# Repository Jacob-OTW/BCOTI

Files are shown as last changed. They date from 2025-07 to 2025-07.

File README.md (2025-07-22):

# BCOTI (Budget-Clip-On-Thermal-Imager)
This project is about building a Clip-On-Thermal-Imager (COTI) for Analog night vision goggles, similar to the Jerry-C, PAS29A/B, etc. yourself.

The current version uses a 256x192@12um sensor with a 9.1mm lens. This combined with the LZE039 and 25mm DCX lens, gives you a 1x 17°x13° thermal overlay in your NVGs. At the moment the image is cropped to a 13°x13° Rectangle.

Cropping it to a 13° circle is also an option by modifying the shape of the `Display_Spacer.step` model.

The unit is powered by a standard USB-C power source delivering 5v.

# User Manual

## Setting image settings

The BCOTI uses the Wi-Fi interface of the esp32 board to act as a web server to host a basic WebUI. To start the unit with Wi-Fi enabled, 

1. hold down the push-button and then supply the unit with power, so either plug in your cable (given the poti is already enabled) or enable the poti, keep the button held down for a short moment, then let go.

2. Open your phones Wi-Fi settings and connect to "BCOTI", the password is "wifipass1234"

3. Inside a web browser, open "192.168.4.1".

4. At the top you select the active preset, so the one being both used by the unit in real time, and the one you make changes to.

5. You can either enable or disable a preset, this determines if the preset will be used, or skipped when using the push button on the unit.

6. Once you made all your changes, reboot the unit to run it on the normal mode. Then use the push button to cycle through your active presets.

### Recommended Settings
- Burn protection. This will automatically close the shutter of the thermal camera if you look at something very hot, like a fire, or the sun. Note that when the unit is not powered, the shutter is in the open position, so it's highly recommended you cover the lens when the unit is not in use. Very hot object can burn the actual sensor.
- Auto Shutter. This will do Non-Uni

# Bill-of-materials
Expect to pay about 400€ (EU) or about 500usd (US) for parts when buying in small quantities

| Part | Cost | Link | Comment |
|---|---|---|---|
| Mini2 | 189€ | [AliExpress (256 9.1mm option)](https://www.aliexpress.us/item/1005007938410808.html) | Only the 256 w/ 9.1mm version will work, others won't be 1x with current setup. [Hdaniee Store page incase the link doesn't work](https://www.aliexpress.com/store/1104212749?spm=a2g0o.detail.0.0.5c38Uf2FUf2Fd3), CV256 9.1mm. [For Some it might also be much cheaper to buy on Alibaba](https://www.alibaba.com/product-detail/HDANIEE-Series-Thermal-Imaging-Camera-Module_1601290252342.html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) |
| LZE039 OLED | 98€ | [AliExpress (AV 3color option)](https://www.aliexpress.us/item/1005008087046449.html) | Bare screen + AV driver. |
| Esp32c3 Super Mini | 2.6€ | [AliExpress](https://www.aliexpress.us/item/1005007663345442.html) | They can break during assembly, I'd recommend a 5pc for safety. |
| USB-C Connector Breakout (1x+) | 2.25€  | [AliExpress 2pc ("TYPE-C male 4P" option)](https://www.aliexpress.us/item/1005005870466748.html) | At least 1x for device internal, but can also be used to created really low profile cable for helmet setup. |
| USB-C Port | 1.49€  | [AliExpress ("4P Black" option)](https://www.aliexpress.us/item/1005005768848819.html) | |
| Toggle Switch | 1.19€  | [AliExpress ("3P 11.7ON-OFF-ON R" option)](https://www.aliexpress.us/item/1005008165436395.html) | |
| Poti w/ ON-OFF-switch | 2.59€  | [AliExpress 5pc ("20K Ohm" option)](https://aliexpress.us/item/1005003523748492.html) | Can also be higher resistance value, for voltage divider, without current draw like here, it doesn't really matter |
| M2x4 Screws (11x) | 1.35€  | [AliExpress 50pc (M2 x 50pc, 4mm length option)](https://www.aliexpress.us/item/1005008314123679.html) | I didn't use these exact ones, but should work, otherwise I adjust the hole size for the screw heads |
| M2x3 Heat Inserts (11x) | 9.99€  | [CNCKitchen 100pc](https://cnckitchen.store/products/heat-set-insert-m2-x-3-100-pieces) | Could also get cheaper ones in similar size, but I like these because they give good info about the required hole sizes. Should you get one with a smaller OD, the FreeCad file has a parameter for that. |
| 5mmD 25mmF DCX lens | 41.61$ | [Edmund Optics](https://www.edmundoptics.com/p/5mm-dia-x-25mm-fl-uncoated-double-convex-lens/18171/) | Price is really bad, but haven't found alternative yet. |
| 5x5x5mm right-angle-prism | 1.99€  | [AliExpress](https://www.aliexpress.com/item/1005008430325318.html) | This replaces the surface mirror used in previous versions, look into the change history for more info. [If the link doesn't work, try this one](https://www.aliexpress.com/item/4001089104491.html) |
| 3mm Elastic band (1m) | 1,99€  | [AliExpress ("3mm 10meters" option)](https://www.aliexpress.us/item/1005008987955538.html) | should be between 2mm and 3mm thickness, you won't actually need a meter, but cutting them to the right sizes sometimes takes a few tries. |
| 26AWG Silicone wire | 10.29€ | [AliExpress ("26 AWG 60m" option)](https://www.aliexpress.us/item/1005005450546335.html) | Any 26AWG (or close to) silicone wire will work, would recommend least 3 unique colors though. |
| O-Ring OD32 CS3.1 | 2.49€  | [AliExpress 50pc ("OD32mm CS3.1mm" option)](https://www.aliexpress.us/item/1005008292700053.html) | Kinda optional, it by itself won't water proof the housing, as there are other way water can still get in besides the edge of the camera-cage, but it's a start. |
| 7mm Momentary Button | 2.99€  | [AliExpress 5pc ("PBS-110 NO Black") option](https://www.aliexpress.us/item/1005008777027854.html) | |
| 1.25mm 5pin jst cable | 2.69€  | [AliExpress ("5set 5pin" option)](https://www.aliexpress.us/item/1005008669994352.html) | |
| Heat shrink tubes | 1.69€  | [AliExpress](https://www.aliexpress.us/item/1005008858472748.html) | |

# Build-Guide

## 3d printed parts

Using a dark material which absorbs light instead of reflecting it is highly recommend.

1. Print the `Body_Shell.step`, `PVS14_Lens_Clip.step`, and `Camera_Cage_x_x_deg.step` with a basic 0.12mm layer height profile.
Change the following
    1. Wall-loops to 3x or 4x. 
    2. Infill to about 22% to 35%
    3. Support to tree

    <br>
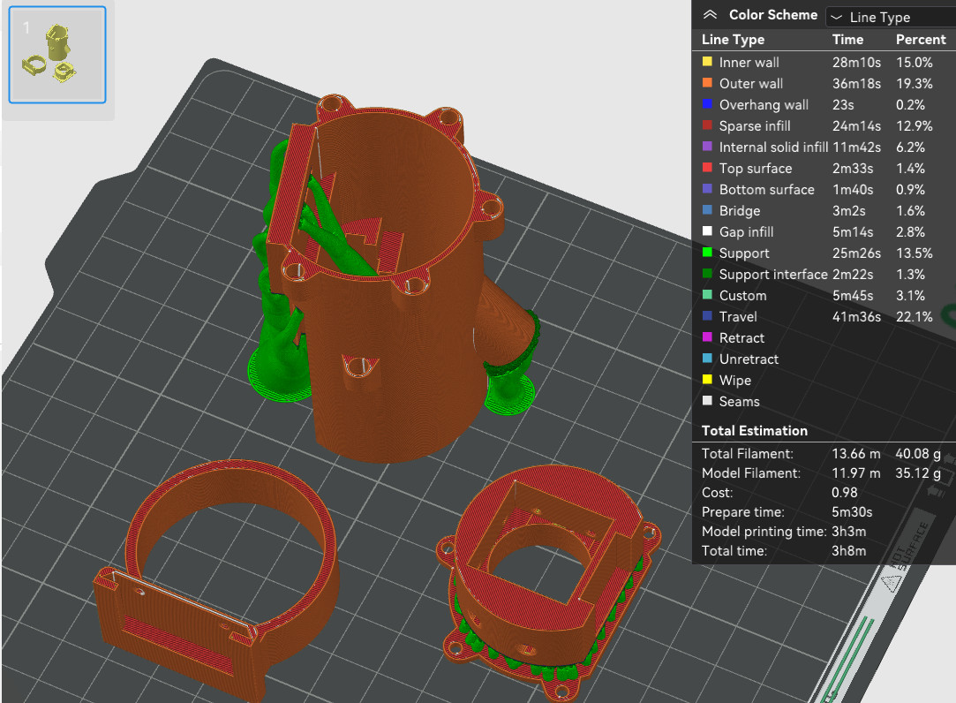
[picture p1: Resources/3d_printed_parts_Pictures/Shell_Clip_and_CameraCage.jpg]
Shell_clip_and_cage_3d_printing
    
    <br>
    I'd recommend adding extra support to the push-button mount hole on the housing shell
    <br>
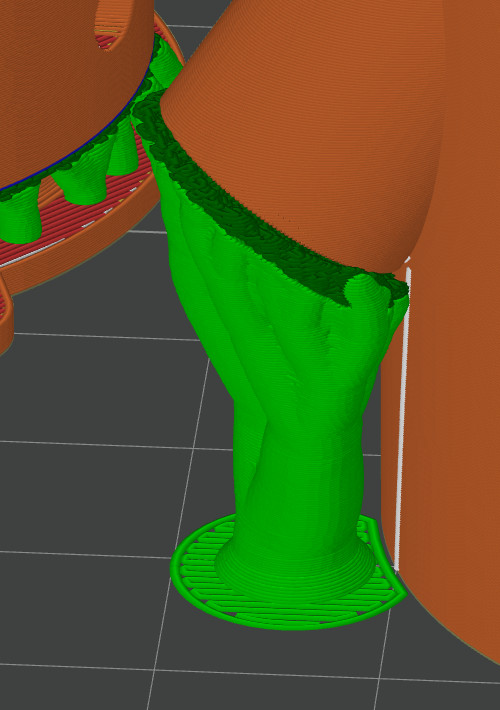
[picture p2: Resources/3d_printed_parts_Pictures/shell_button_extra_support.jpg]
Extra_support
    

2. Print the periscope like shown in the picture. <=0.12mm layer height, and I'd recommend "Snug" supports.
<br>
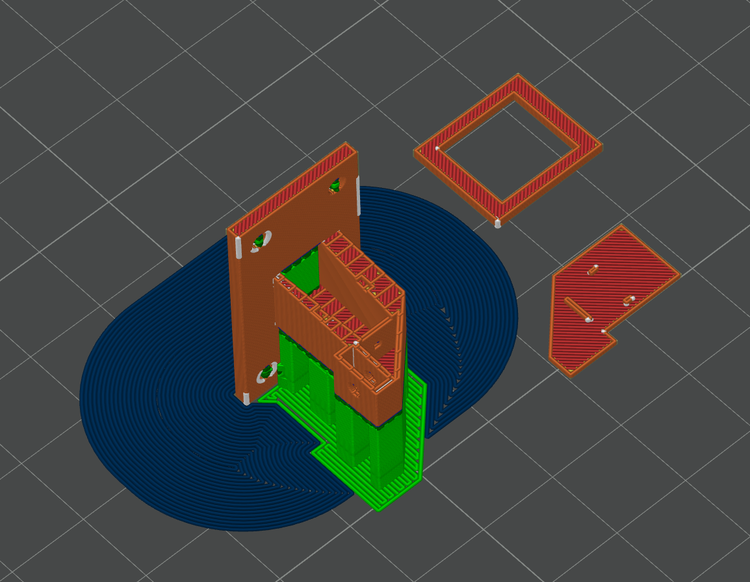
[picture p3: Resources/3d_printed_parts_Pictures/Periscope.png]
Periscope print oriantation

<br>
After the print, press fit the prism and DCX lens into the periscope. After checking functionally, you can glue on the side cover

3. (Optional, but recommended) print the `Bikini_Cover_TPU.step` out of a fairly soft TPU. I printed mine out of 95A Overture TPU

## Electronics

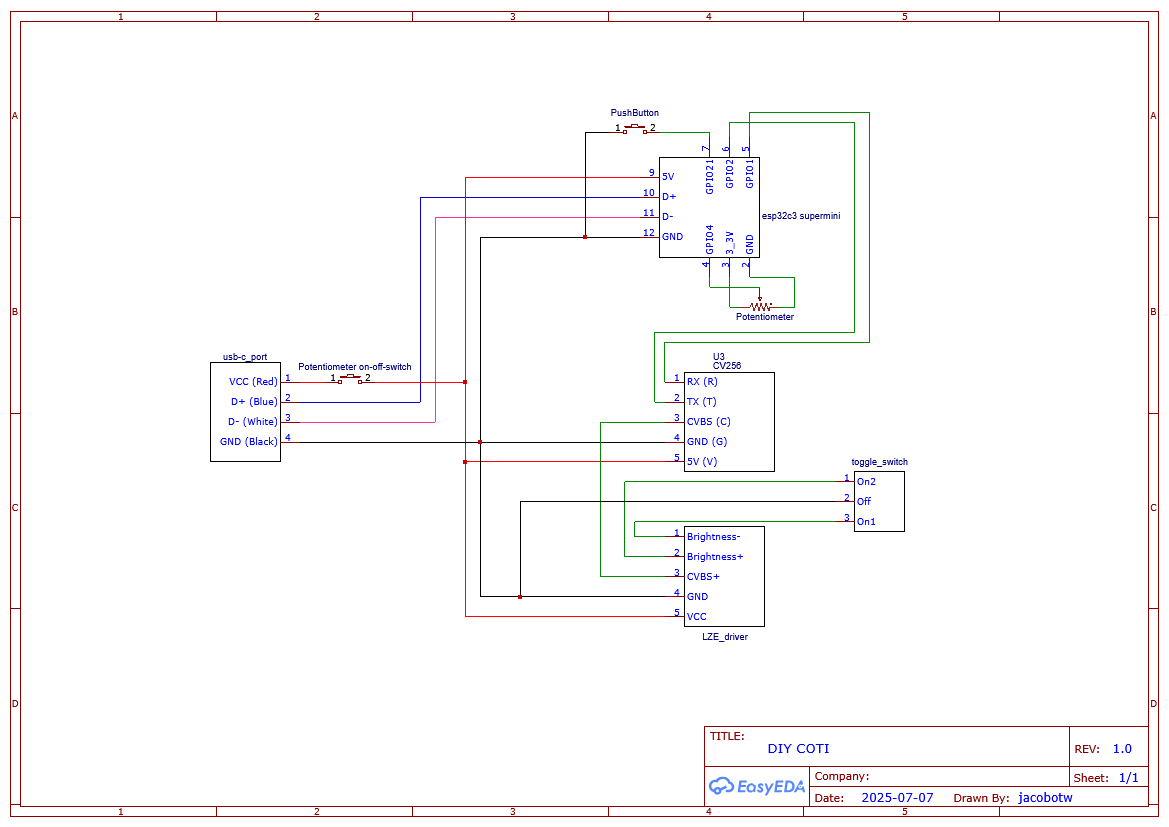
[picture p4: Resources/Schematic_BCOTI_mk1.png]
wiring_diagram


### Step-by-step

Using Heat shrink for all connections where possible is recommended.

1. Cut the cables of the USB-C port to a length of around 80mm.
2. Cut a 1x 80mm piece of (Red) wire. And 3x 30mm pieces of (Red) Wire. These will be your 5V-net. Strip a portion of the installation on one side so that you can twist together the 3x short pieces, then cover in solder.
3. Cut 5x 30mm pieces of black wire. These will be your ground-net. Strip one side and combine the 5pieces, same as you did for the 5v-net.
4. Solder the 80mm piece of (Red) wire, to the potentiometer's on-off-switch.
<br>
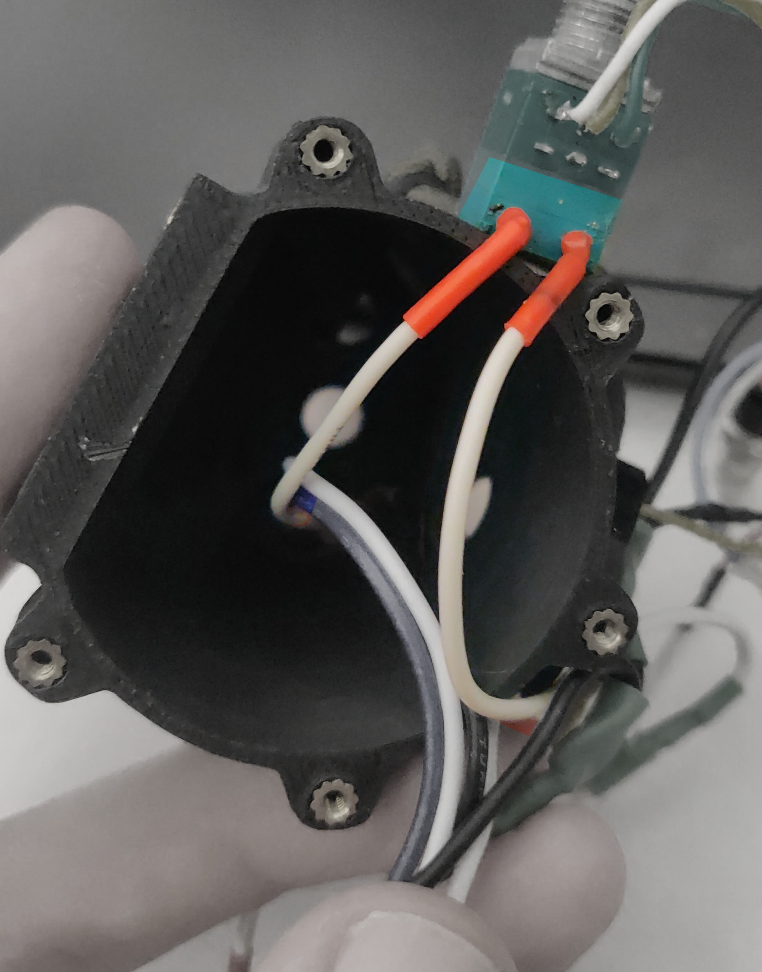
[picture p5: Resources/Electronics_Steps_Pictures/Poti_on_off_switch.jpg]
Poti_On_Off_Switch

(picture shows USB-C Port wire already connector, this is done during assembly)

5. Solder the bundle of 3 (Red) wires to the 80mm piece from the previous step.
<br>
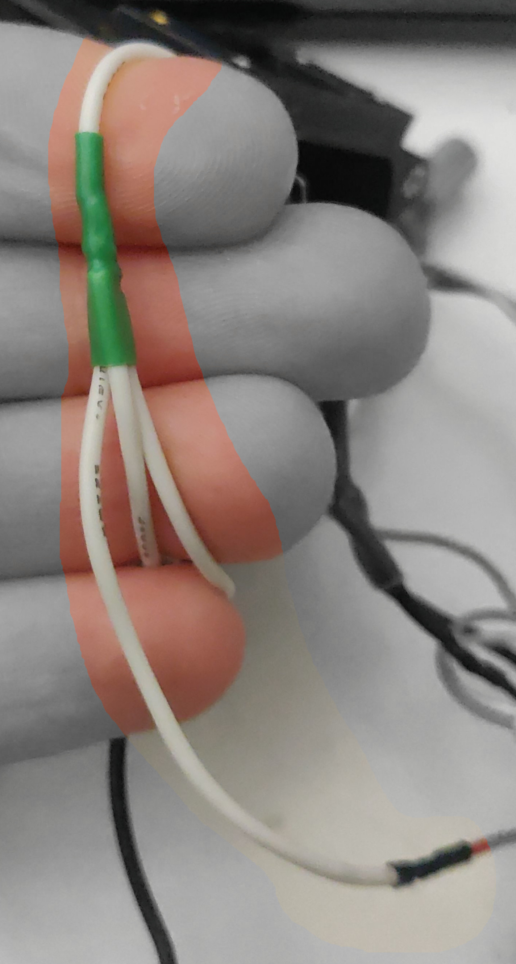
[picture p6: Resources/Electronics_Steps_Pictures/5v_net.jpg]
5v_net


6. Attach the 5v wires, as well as ground to the USB-C breakout board, the display driver connector, and the camera connector, as shown in the diagram.

7. Connect ground wires to the push-button, and on-off-on toggle switch.

8. Cut a 50mm piece of wire, solder one end to the push button, and the other to under side, facing inwards to the esp32c3's GPIO21 pin.
<br>
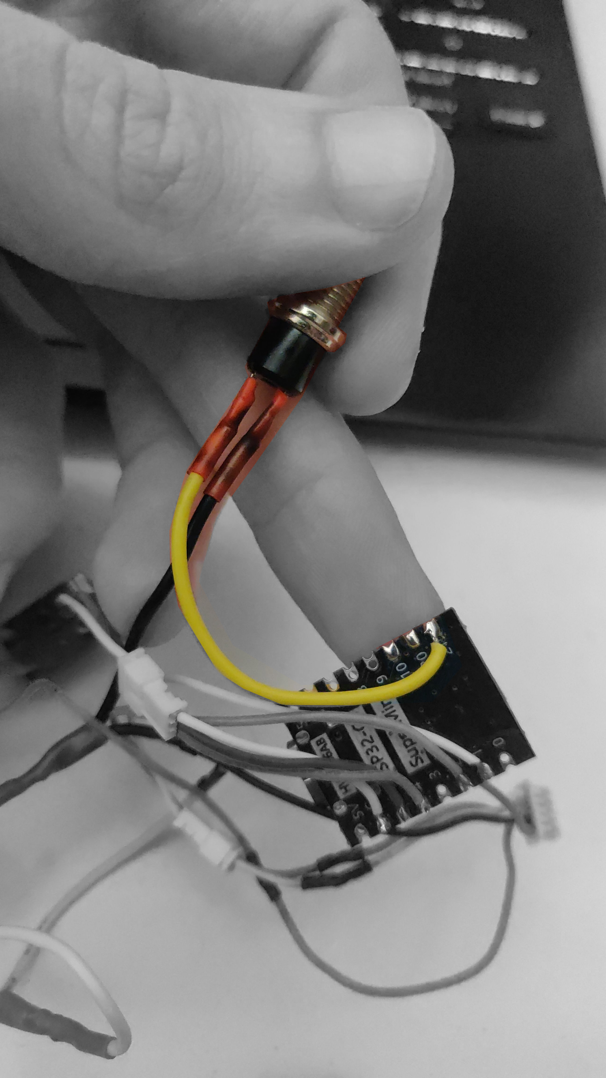
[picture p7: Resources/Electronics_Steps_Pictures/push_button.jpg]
Push_button

9. Cut the `brightness+` and `brightness-` cables of the display driver to a length of about 70mm, then attach them to the `on`-terminals of the toggle-switch.
<br>
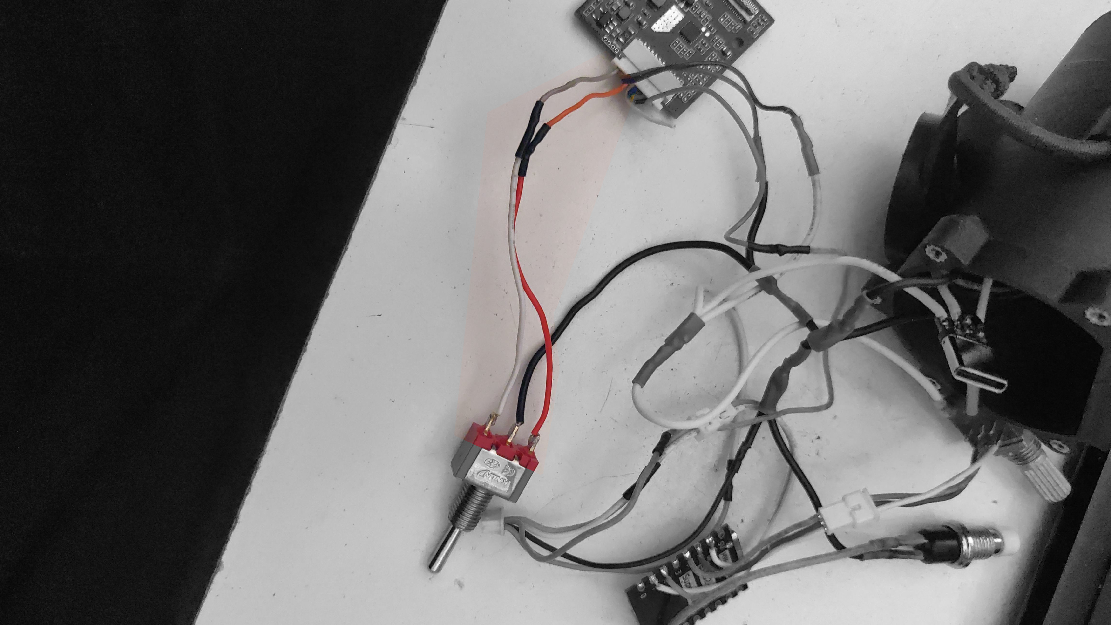
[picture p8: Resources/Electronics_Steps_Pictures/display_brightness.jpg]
Brightness_switch

10. Connect the white wire of the usb-c port to the D- Pad of the USB-C breakout board, and the blue wire to D+.
<br>
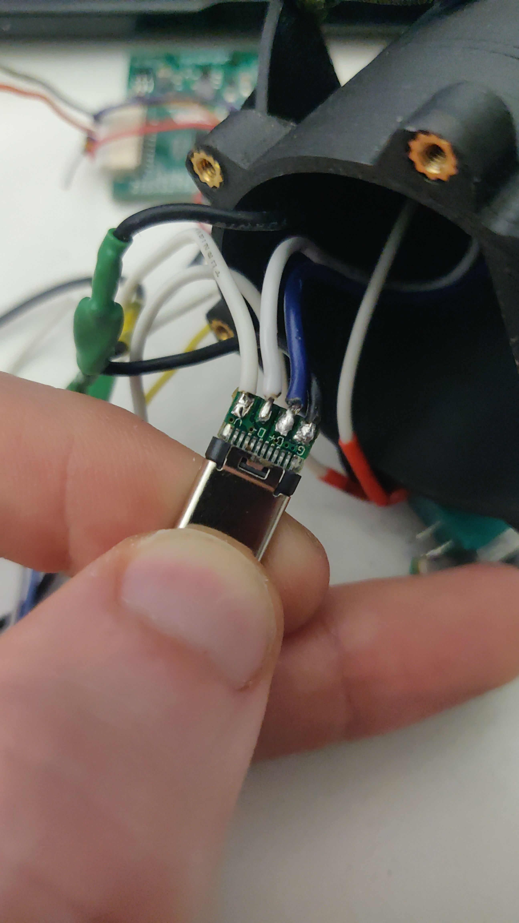
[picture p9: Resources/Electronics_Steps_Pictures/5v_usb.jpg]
USB_C_Port_to_connector

11. Connect the RX wire of the camera to GPIO1, and the TX wire to GPIO2 of the esp32c3 board. The cables should be attached on the underside facing inwards.
<br>
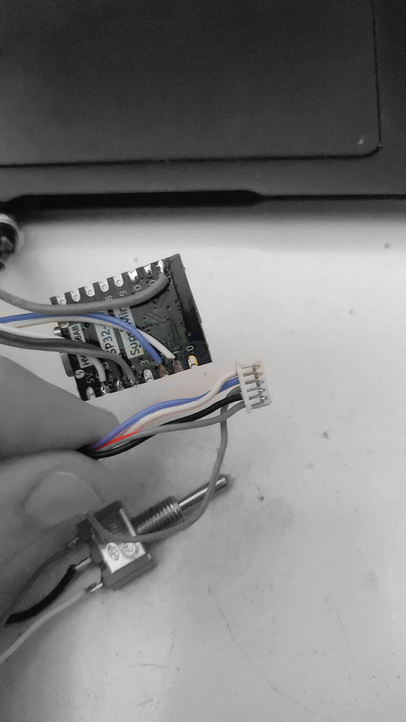
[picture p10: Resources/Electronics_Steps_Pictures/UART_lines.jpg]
UART_lines

12. Using 3x 50mm pieces of wire, connect the potentiometer to the esp32 board like shown in the schematic. Ground should be on the left, sense-wire (GPIO4) in the centre, and 3.3v on the right, that way the power goes from 0v to 3.3v when it's turned up, instead of being reversed.
<br>
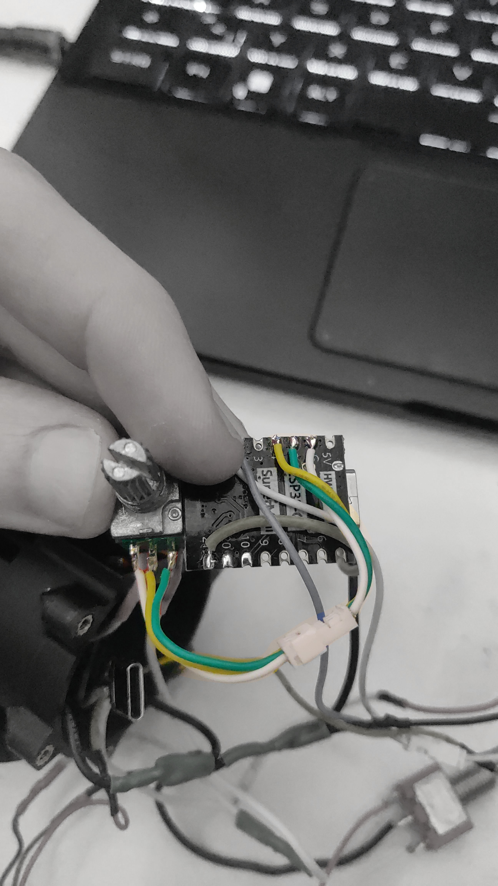
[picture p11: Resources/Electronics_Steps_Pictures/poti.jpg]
Poti_Voltage_Dividier

13. Connect the Video-out of the camera to the `CVBS+` cable of the display driver. Total wire length is recommended at 130mm. 

## Assembly

1. Insert the USB-C Port into the housing.

2. Solder the 5v wire of the Port to the on-off-switch of the potentiometer

3. Insert the potentiometer into the shell (from the inside) with the pins pointing down, and fix in place the with the Nut and washer.
<br>
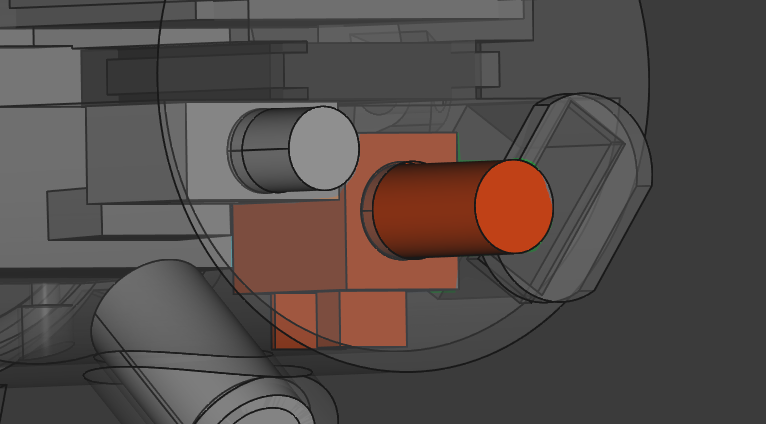
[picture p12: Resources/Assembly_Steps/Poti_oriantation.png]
potentiometer oriantation


4. Insert the Brightness Toggle switch (horizontal orientation), and fix in place with washer and nut.
<br>
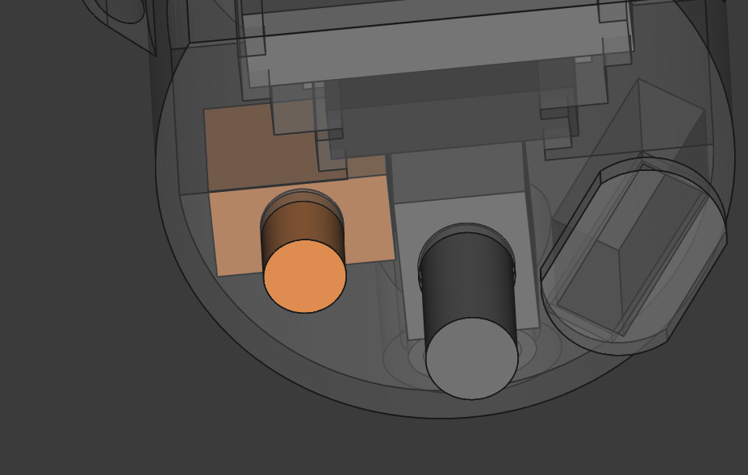
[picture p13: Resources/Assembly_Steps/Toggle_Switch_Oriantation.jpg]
toggle switch oriantation


5. With the USB-Port facing down, and the usb-c breakout connector inserted, insert the esp32 board into the centre slot of the shell
<br>
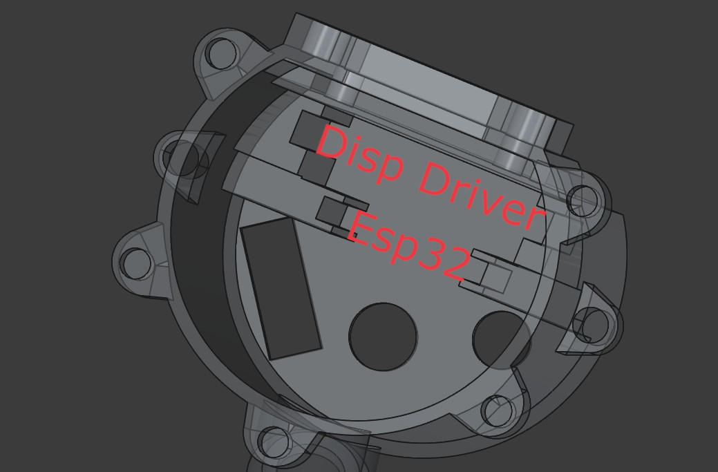
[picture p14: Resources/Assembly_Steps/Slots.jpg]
Shell Slots


6. Disconnect the display from the driver, and insert the FPC through the hole of the slot for the display.

7. Connect the display to the driver again, then insert the driver (with the wires pointing into the shell) into the slot.

8. Insert the push-button into the slot on the bottom of the shell, and fix it in place with the nut and washer.

9. Wrap the O-Ring around the CameraCage, and insert the camera module (with the JST connector facing down, away from the slot in the top of the cage), then fix in place with all 6x M2x4 sews. Tighten them evenly, instead of doing one fully after the other.

10. Check if the camera cage can be fully inserted without putting pressure on the display FPC or any components inside the shell.

11. Insert the 11x heat inserts into the holes with your soldering iron.

12. Attach the Lens clip, Periscope, and Camera cage with the 11x M2x4 screws.

13. Attach the unit to your NV device and check the alignment of the image. (Should the image be mirrored incorrectly, adjust it via the WebUI's "Flip Mode" setting)
    1. Attach the unit like shown in the picture, so hanging straight down from your NV unit
    <br>
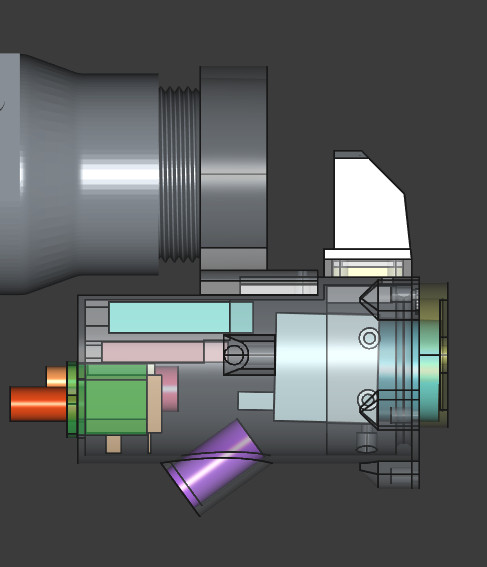
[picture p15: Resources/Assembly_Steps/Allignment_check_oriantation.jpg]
bottom_hanging allignment
    

    2. If the thermal image is too far left or right, check that the camera cage is properly installed. This usually isn't an issue.

    3. If the thermal image is too far up or down, you can reprint the CameraCage with a different offset. If the overlay it too high, the camera needs to look up more. I plan to have a way of mechanically adjusting the camera position via screws, but this is not ready yet.

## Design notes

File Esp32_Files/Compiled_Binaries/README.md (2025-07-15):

# Flashing compiled binaries

Flashing the esp32c3 super mini board via the web browser is only possilbe while having physcial accses to the "boot" button. Methode via esptool.py will also work via the usb-dataline pass through of the usb-c port on the housing. 

## esptool.py

Use the following command to flash `esptool.py` (included in esp-idf, and arduino-esp32 core installations)

`esptool.py -p COM1 -b 460800 --before default_reset --after hard_reset --chip esp32c3 write_flash --flash_mode dio --flash_freq 80m --flash_size detect 0x0 bootloader.bin 0x10000 DIY_COTI.bin 0x8000 partition-table.bin`

## web browser

1. Visit [esp.huhn.me](https://esp.huhn.me/) (recommend via chrome browser, others may not work)

2. Hold down the boot button, then insert the usb cable, then let go of the button.

3. Click connect, and select the serial-port of the esp32 board.

4. Add the following files at the given flash-offsets

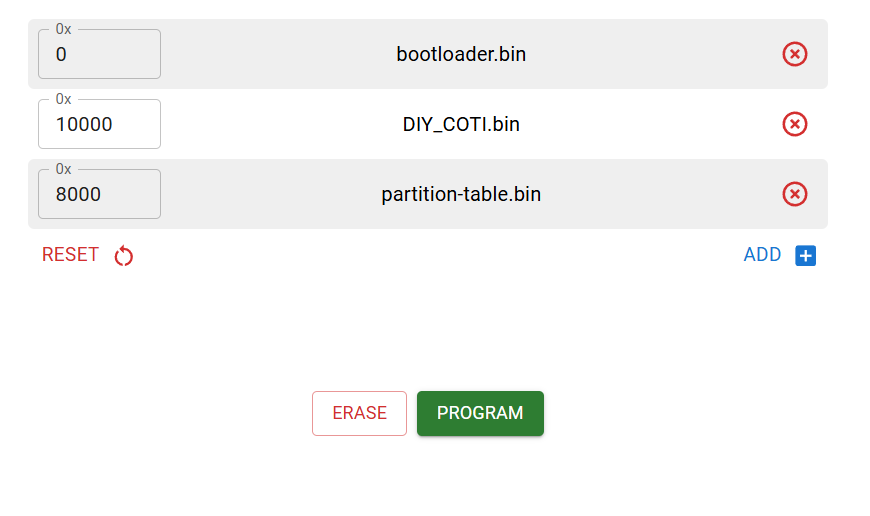
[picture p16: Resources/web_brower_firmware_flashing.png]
Files and offsets

(bootloader.bin at 0, DIY_COTI.bin at 10000, and partition-table.bin at 0x8000)

5. Then click "PROGRAM"

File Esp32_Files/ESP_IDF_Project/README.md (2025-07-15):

# Esp32 DIY COTI firmware

Compiled with esp_idf v5.3.1

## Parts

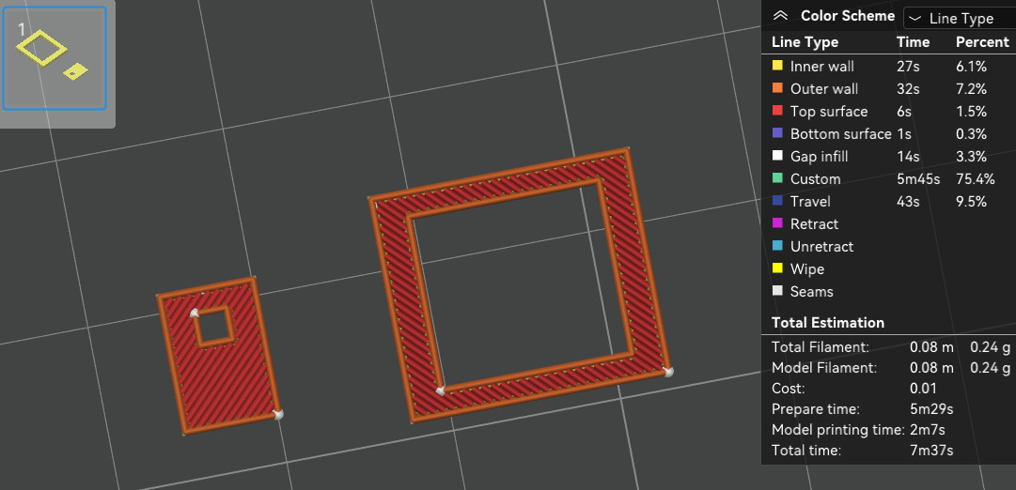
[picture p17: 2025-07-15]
Resources/3d_printed_parts_Pictures/cover_and_spacer.jpg

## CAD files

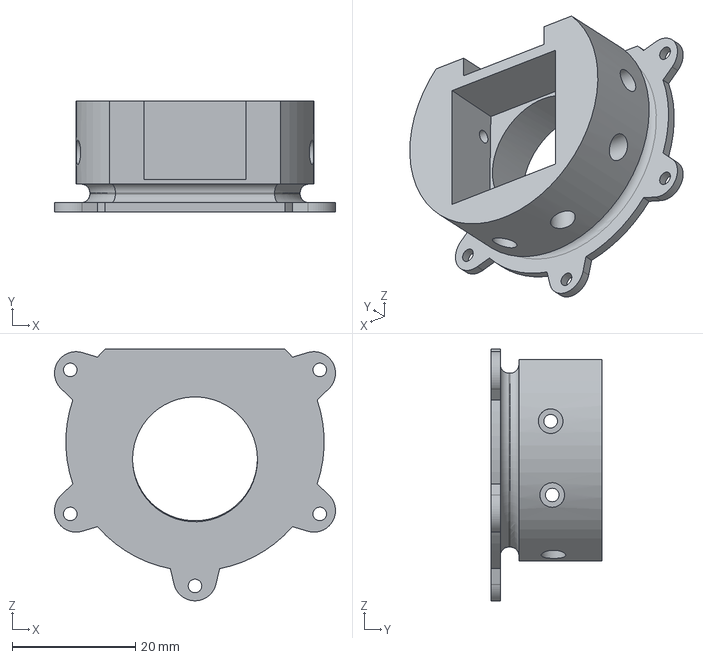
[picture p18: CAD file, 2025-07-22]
CAD_Files/Other_CameraCage_Offsets/CameraCage_1_2_deg.step
45.7 x 18.0 x 40.9 mm

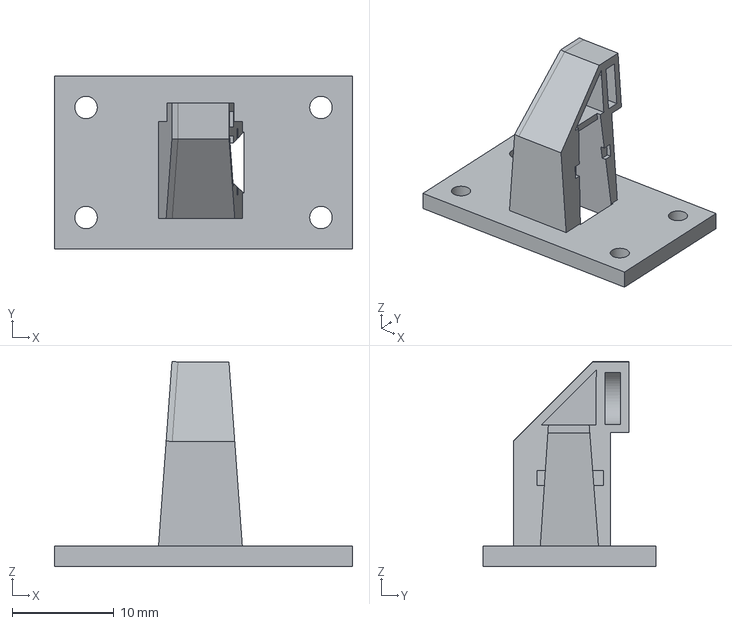
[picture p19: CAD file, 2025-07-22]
CAD_Files/Stem.step
29.2 x 17.0 x 20.1 mm

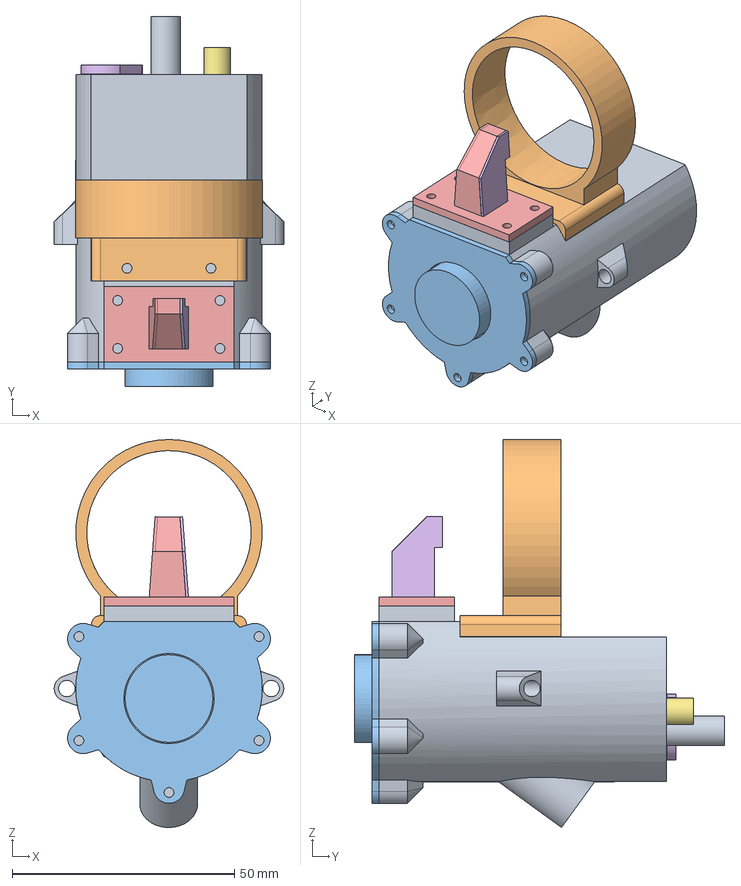
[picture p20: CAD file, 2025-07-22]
CAD_Files/DIY_COTI.FCStd
51.7 x 83.4 x 87.4 mm
Potentiometer
Display
Mini2
DisplayDriver
Esp32
USB-C
RockerSwitch
Button
RoundShell
PVS14LensClip
CameraCage
DisplaySpacer
Stem
StemCover

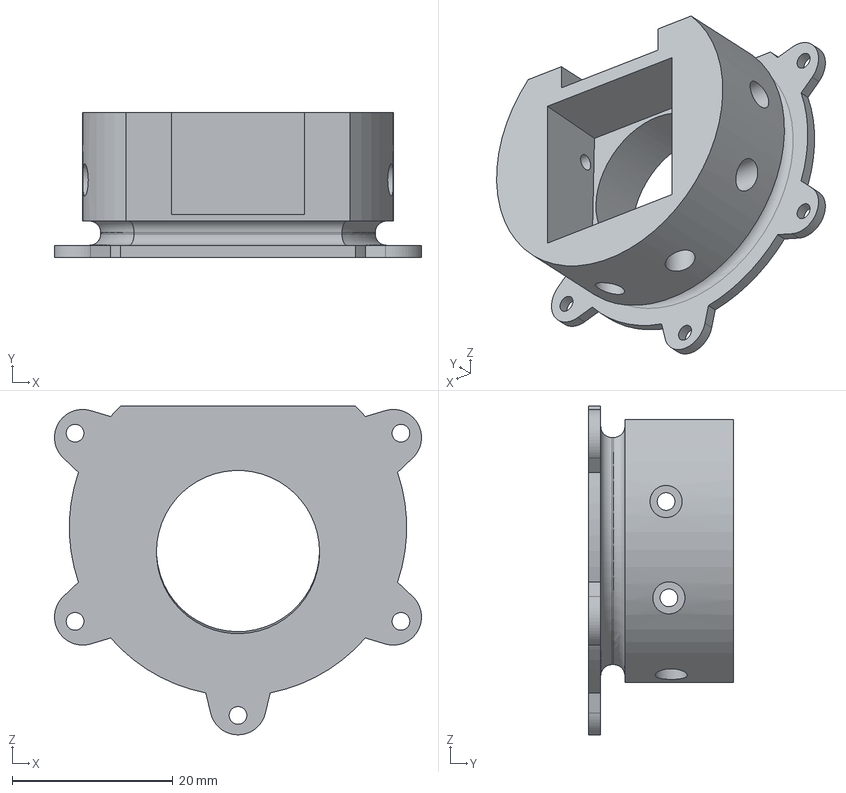
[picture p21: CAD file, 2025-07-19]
CAD_Files/Other_CameraCage_Offsets/CameraCage_1_7_deg.step
45.7 x 18.0 x 40.9 mm

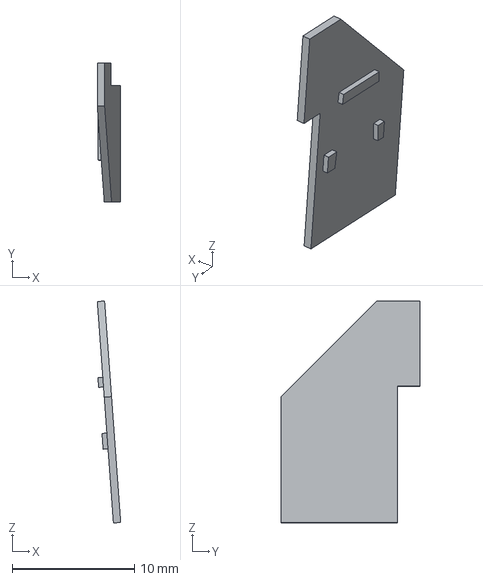
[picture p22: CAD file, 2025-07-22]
CAD_Files/StemCover.step
1.91 x 11.3 x 18.1 mm

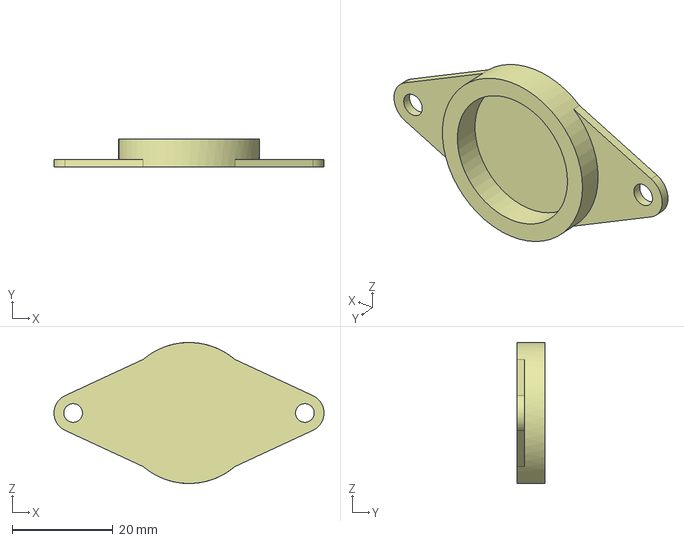
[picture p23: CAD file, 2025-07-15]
CAD_Files/Bikini_Cover_TPU.step
53.6 x 5.50 x 28.0 mm

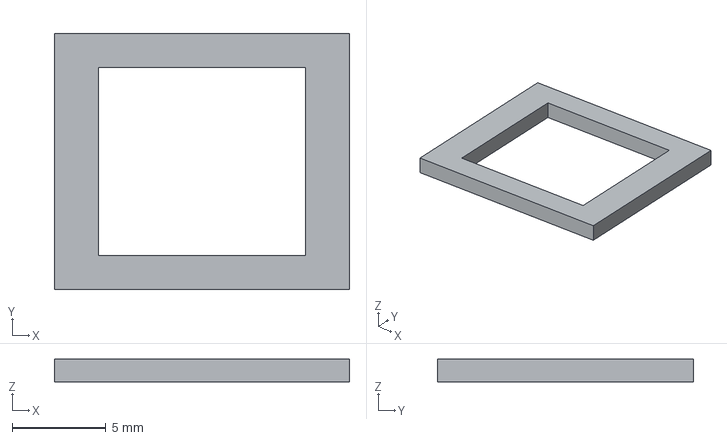
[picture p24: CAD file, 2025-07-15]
CAD_Files/Display_Spacer.step
15.7 x 13.7 x 1.20 mm

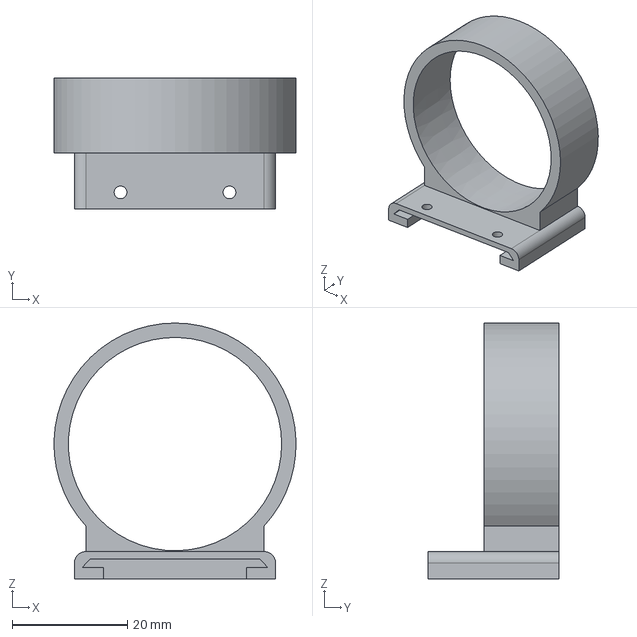
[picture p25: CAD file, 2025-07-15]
CAD_Files/PVS14_Lens_Clip.step
42.0 x 22.8 x 44.4 mm

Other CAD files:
CAD_Files/Other_CameraCage_Offsets/CameraCage_1_8_deg.step
CAD_Files/CameraCag.step
CAD_Files/Other_CameraCage_Offsets/CameraCage_1_5_deg.step
CAD_Files/CameraCage_1_2_deg.step
CAD_Files/Other_CameraCage_Offsets/CameraCage_1_9_deg.step
CAD_Files/Other_CameraCage_Offsets/CameraCage_1_1_deg.step
CAD_Files/Other_CameraCage_Offsets/CameraCage_1_3_deg.step
CAD_Files/CameraCage_1_5_deg.step
CAD_Files/Other_CameraCage_Offsets/CameraCage_1_4_deg.step
CAD_Files/Other_CameraCage_Offsets/CameraCage_2_0_deg.step
CAD_Files/Body_Shell.step
CAD_Files/Other_CameraCage_Offsets/CameraCage_1_0_deg.step
CAD_Files/Other_CameraCage_Offsets/CameraCage_1_6_deg.step

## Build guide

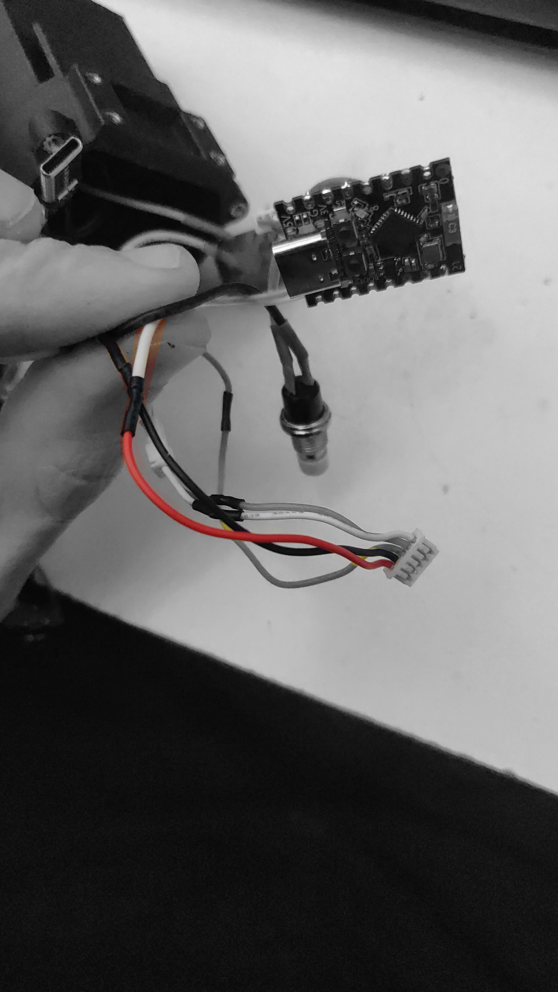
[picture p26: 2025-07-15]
Resources/Electronics_Steps_Pictures/5v_camera.jpg

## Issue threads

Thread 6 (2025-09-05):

Flip mode + alignment

marhub, 2025-09-05:
For some reason, I need to set flip mode on the Y axis. But then the alignment sliders disapear.
Why is that?

Jacob-OTW, 2025-09-05:
The Mini2 can either mirror the image, or do digital zoom, not both at once. If you want to do digital alignment, you need the modified display driver that can mirror the image. If you buy a parts kit from m4rs, who organises the group-buys for the US, you'll get that driver.

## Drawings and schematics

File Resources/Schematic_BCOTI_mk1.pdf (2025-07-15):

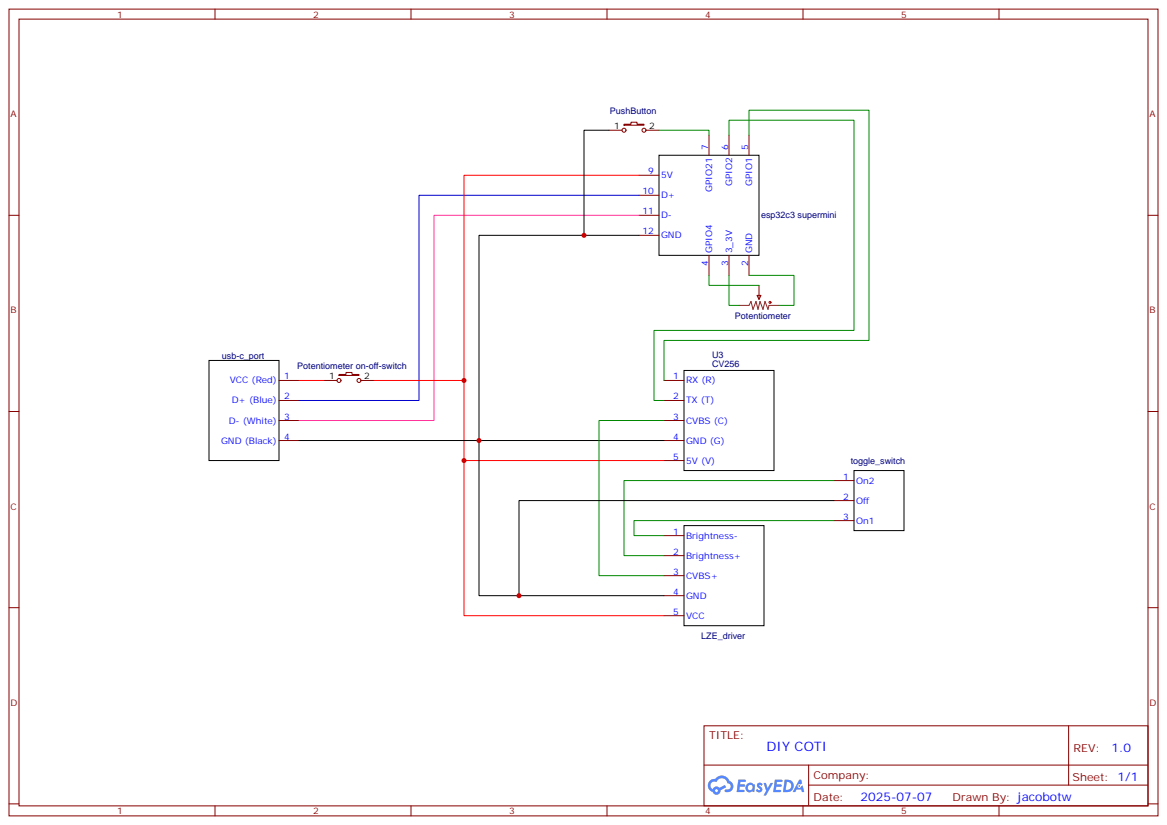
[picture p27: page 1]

Potentiometer on-off-switch

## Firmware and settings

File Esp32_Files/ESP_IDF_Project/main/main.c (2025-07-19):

#include <stdio.h>
#include <stdlib.h>
#include "esp_wifi.h"
#include "esp_mac.h"
#include "esp_event.h"
#include "lwip/err.h"
#include "lwip/sys.h"
#include "esp_log.h"
#include "nvs_flash.h"
#include "esp_http_server.h"
#include "esp_system.h"
#include "json_parser.h"
#include "esp_adc/adc_oneshot.h"
#include "esp_timer.h"
#include "driver/gpio.h"
#include <math.h>
#include "Mini2.h"

#define TAG "MAIN"

#define SSID "BCOTI"
#define PASSWORD "wifipass1234"
#define PRESET_COUNT 5

#define UART_TX GPIO_NUM_1
#define UART_RX GPIO_NUM_2
#define POTI_PIN GPIO_NUM_4
#define MULTI_BTN GPIO_NUM_21

volatile int64_t button_debouce;

extern const uint8_t index_html_start[] asm("_binary_index_html_start");
extern const uint8_t index_html_end[]   asm("_binary_index_html_end");

static esp_netif_t *sta_netif = NULL;

nvs_handle_t flash_handle;

int8_t brightness_button_count = 0;

typedef struct stored_values_t{
    uint8_t active_preset;
    value_preset_t presets[PRESET_COUNT];
} stored_values_t;

value_preset_t default_preset = {
    .preset_en = false,
    .pseudo_color = WHOT,
    .scene_mode = Outline,
    .flip_mode = X_Flip,
    .av_format = PAL,
    .contrast = 50,
    .edge_enhancment_gear = 1,
    .detail_enhancement_gear = 50,
    .burn_protection_en = true,
    .auto_shutter_en = true,
    .fps = Hz50,
    .breathing = false,
};

stored_values_t stored = {
    .active_preset = 0,
};

Mini2_t cam = {
    .uart_port = UART_NUM_1, // C3 only has num0 and num1, and num0 is used for debug / USB_CDC
    .uart_tx = UART_TX,
    .uart_rx = UART_RX,
    .variant = Mini2_256
};

static void wifi_event_handler(void* arg, esp_event_base_t event_base, int32_t event_id, void* event_data) {
    if (event_id == WIFI_EVENT_AP_STACONNECTED) {
        wifi_event_ap_staconnected_t* event = (wifi_event_ap_staconnected_t*) event_data;
        ESP_LOGI(TAG, "station "MACSTR" join, AID=%d",
                 MAC2STR(event->mac), event->aid);
    } else if (event_id == WIFI_EVENT_AP_STADISCONNECTED) {
        wifi_event_ap_stadisconnected_t* event = (wifi_event_ap_stadisconnected_t*) event_data;
        ESP_LOGI(TAG, "station "MACSTR" leave, AID=%d, reason=%d",
                 MAC2STR(event->mac), event->aid, event->reason);
    }
}

void next_preset() { // Preset0 is always seen  active, otherwise the esp32 could crash because it got stuck in a loop during ISR
    stored.active_preset = (stored.active_preset + 1) % PRESET_COUNT;
    if (stored.active_preset != 0 && !stored.presets[stored.active_preset].preset_en) {
        next_preset();
    }
}

void IRAM_ATTR button_isr_handler(void* arg) {
    if (esp_timer_get_time() - button_debouce > 200000) { // 200ms debounce
        button_debouce = esp_timer_get_time();
        next_preset();
    };
}

static void loop_task(void *pvParameters) {
    int max_gain = 0;
    int64_t breathing_time_out = 0;
    #define breathing_pause_time_us (2 * 1000 * 1000)

    uint8_t last_seen_preset = stored.active_preset;

    adc_unit_t unit;
    adc_channel_t channel;
    esp_err_t err = adc_oneshot_io_to_channel(POTI_PIN, &unit, &channel);
    if (err != ESP_OK) {
        ESP_LOGE(TAG, "Failed to get info about GPIO5");
    }

    int adc_raw;
    int last_adc_val = 0;
    adc_oneshot_unit_handle_t adc_handle;
    adc_oneshot_unit_init_cfg_t init_config = {
        .unit_id = unit,
        .ulp_mode = ADC_ULP_MODE_DISABLE,
    };
    ESP_ERROR_CHECK(adc_oneshot_new_unit(&init_config, &adc_handle));

    adc_oneshot_chan_cfg_t config = {
        .bitwidth = ADC_BITWIDTH_DEFAULT,
        .atten = ADC_ATTEN_DB_12,
    };

    ESP_ERROR_CHECK(adc_oneshot_config_channel(adc_handle, channel, &config));

    while (true) {
        adc_oneshot_read(adc_handle, channel, &adc_raw);
        if (abs(adc_raw - last_adc_val) >= 100) {
            last_adc_val = adc_raw;
            float new_brightness = ((float)adc_raw / 4095.0) * 100.0;
            max_gain = (int)new_brightness;
            Mini2_set_brightness(&cam, max_gain);
            breathing_time_out = esp_timer_get_time();
        }
        if (stored.presets[stored.active_preset].breathing && (esp_timer_get_time() - breathing_time_out) >= breathing_pause_time_us) {
            int x_ms = (esp_timer_get_time() - breathing_time_out - breathing_pause_time_us) / 1000;
            float value = (cos(((float)x_ms / 1000.0) * M_PI) + 1.0) / 2;
            // ESP_LOGW(TAG, "Set: %d from %f (value) and %d (max gain)", (int)(value * (float)max_gain), value, max_gain);
            Mini2_set_brightness(&cam, (int)(value * (float)max_gain));
        }
        if (stored.active_preset != last_seen_preset) {
            Mini2_apply_preset(&cam, &stored.presets[stored.active_preset]);
            last_seen_preset = stored.active_preset;
        }
        vTaskDelay(pdMS_TO_TICKS(50));
    }
    
}

/*DIY COTI specific*/

static esp_err_t post_handler(httpd_req_t *req) {
    int ret;

    char* buf = (char*)malloc(req->content_len);

    jparse_ctx_t jctx;

    if (buf != NULL) {
        int bytes_read = httpd_req_recv(req, buf, req->content_len);

        ESP_LOG_BUFFER_HEXDUMP(TAG, buf, bytes_read, ESP_LOG_WARN);

        ret = json_parse_start(&jctx, buf, bytes_read);
        if (ret != OS_SUCCESS) {
            ESP_LOGE(TAG, "Parser failed");
            return ESP_FAIL;
        }
        
        int value;
        ret = json_obj_get_int(&jctx, "pseudo_color", &value);
        if (ret == OS_SUCCESS) {
            Mini2_set_color_pallet(&cam, (enum PseudoColor)value);
            stored.presets[stored.active_preset].pseudo_color = (enum PseudoColor)value;
        }
        ret = json_obj_get_int(&jctx, "scene_mode", &value);
        if (ret == OS_SUCCESS) {
            Mini2_set_scene_mode(&cam, (enum SceneMode)value);
            stored.presets[stored.active_preset].scene_mode = (enum PseudoColor)value;
        }
        ret = json_obj_get_int(&jctx, "flip_mode", &value);
        if (ret == OS_SUCCESS) {
            Mini2_set_flip_mode(&cam, (enum FlipMode)value);
            stored.presets[stored.active_preset].flip_mode = (enum FlipMode)value;
        }
        ret = json_obj_get_int(&jctx, "av_format", &value);
        if (ret == OS_SUCCESS) {
            Mini2_set_analog_video_format(&cam, (enum AnalogVideoFormat)value);
            stored.presets[stored.active_preset].av_format = (enum PseudoColor)value;
        }
        /* Brightness is done via Poti, so no need
                ret = json_obj_get_int(&jctx, "brightness", &value);
        if (ret == OS_SUCCESS) {
            Mini2_set_brightness(&cam, value);
            stored.presets[stored.active_preset].brightness = value;
        }
        */
        ret = json_obj_get_int(&jctx, "contrast", &value);
        if (ret == OS_SUCCESS) {
            Mini2_set_contrast(&cam, value);
            stored.presets[stored.active_preset].contrast = value;
        }
        ret = json_obj_get_int(&jctx, "edge_enhancment_gear", &value);
        if (ret == OS_SUCCESS) {
            Mini2_set_edge_enhancment(&cam, value);
            stored.presets[stored.active_preset].edge_enhancment_gear = value;
        }
        ret = json_obj_get_int(&jctx, "detail_enhancement_gear", &value);
        if (ret == OS_SUCCESS) {
            Mini2_set_detail_enhancement(&cam, value);
            stored.presets[stored.active_preset].detail_enhancement_gear = value;
        }

        bool bool_val;
        ret = json_obj_get_bool(&jctx, "burn_protection_en", &bool_val);
        if (ret == OS_SUCCESS) {
            Mini2_set_burn_protection(&cam, bool_val);
            stored.presets[stored.active_preset].burn_protection_en = bool_val;
        }
        ret = json_obj_get_bool(&jctx, "auto_shutter_en", &bool_val);
        if (ret == OS_SUCCESS) {
            Mini2_set_auto_shutter(&cam, bool_val);
            stored.presets[stored.active_preset].auto_shutter_en = bool_val;
        }

        ret = json_obj_get_bool(&jctx, "breathing", &bool_val);
        if (ret == OS_SUCCESS) {
            stored.presets[stored.active_preset].breathing = bool_val;
        }

        ret = json_obj_get_bool(&jctx, "preset_en", &bool_val);
        if (ret == OS_SUCCESS) {
            if (stored.active_preset == 0) {
                stored.presets[stored.active_preset].preset_en = true; // Preset0 is always enabled.
            } else {
                stored.presets[stored.active_preset].preset_en = bool_val;
            }
        }

        /* Conflicts with Mirror feature
        ret = json_obj_get_object(&jctx, "zoom");
        if (ret == OS_SUCCESS) {
            int x, y, zoom;
            if (json_obj_get_int(&jctx, "x", &x) == OS_SUCCESS && json_obj_get_int(&jctx, "y", &y) == OS_SUCCESS && json_obj_get_int(&jctx, "zoom", &zoom) == OS_SUCCESS) {
                Mini2_set_point_zoom(&cam, (uint16_t)x, (uint16_t)y, (uint8_t)zoom);
                stored.presets[stored.active_preset].zoom = zoom;
                stored.presets[stored.active_preset].zoom_x = x;
                stored.presets[stored.active_preset].zoom_y = y;
            }
            json_obj_leave_object(&jctx);
        }
        */

        ret = json_obj_get_int(&jctx, "active_profile", &value);
        if (ret == OS_SUCCESS) {
            if ((0 <= value) && (value < PRESET_COUNT)) {
                stored.active_preset = value;
                Mini2_apply_preset(&cam, &stored.presets[stored.active_preset]);
            } else {
                ESP_LOGE(TAG, "Active profile number would be out-of-bounds!");
            }   
        }

        ret = json_obj_get_bool(&jctx, "NUC", &bool_val);
        if (ret == OS_SUCCESS && bool_val) {
            Mini2_NUC(&cam);
        }

        ret = json_obj_get_bool(&jctx, "BG", &bool_val);
        if (ret == OS_SUCCESS && bool_val) {
            Mini2_Background_Correction(&cam);
        }

        ret = json_obj_get_bool(&jctx, "parameters_save", &bool_val);
        if (ret == OS_SUCCESS && bool_val) {
            Mini2_parameters_save(&cam);
        }

        httpd_resp_send_chunk(req, NULL, 0);
    }
    
    json_parse_end(&jctx);
    free(buf);

    esp_err_t err = nvs_set_blob(flash_handle, "stored_values", &stored, sizeof(stored_values_t));
    if (err == ESP_OK) {
        ESP_LOGI(TAG, "Stored values in NVS");
    } else {
        ESP_LOGE(TAG, "Unable to store values in NVS");
    }
    return ESP_OK;
}

static esp_err_t retireve_values(httpd_req_t *req) {
    static char out_format[] = "{ \
    \"preset_count\": %u, \
    \"active_profile\": %u, \
    \"preset_en\": %u, \
    \"pseudo_color\": %u, \
    \"scene_mode\": %u, \
    \"contrast\": %u, \
    \"edge_enhancment_gear\": %u, \
    \"detail_enhancement_gear\": %u, \
    \"burn_protection_en\": %u, \
    \"auto_shutter_en\": %u, \
    \"breathing\": %u, \
    \"flip_mode\": %u, \
    \"zoom\": %u, \
    \"zoom_x\": %u, \
    \"zoom_y\": %u, \
    \"sensor_width\": %u, \
    \"sensor_height\": %u \
    }";

    char out_json[512];

    int res = snprintf(out_json, sizeof(out_json), out_format,
        PRESET_COUNT,
        stored.active_preset,
        (uint8_t)stored.presets[stored.active_preset].preset_en,
        (uint8_t)stored.presets[stored.active_preset].pseudo_color,
        (uint8_t)stored.presets[stored.active_preset].scene_mode,
        stored.presets[stored.active_preset].contrast,
        stored.presets[stored.active_preset].edge_enhancment_gear,
        stored.presets[stored.active_preset].detail_enhancement_gear,
        (uint8_t)stored.presets[stored.active_preset].burn_protection_en,
        (uint8_t)stored.presets[stored.active_preset].auto_shutter_en,
        (uint8_t)stored.presets[stored.active_preset].breathing,
        (uint8_t)stored.presets[stored.active_preset].flip_mode,
        stored.presets[stored.active_preset].zoom,
        stored.presets[stored.active_preset].zoom_x,
        stored.presets[stored.active_preset].zoom_y,
        cam.variant.sensor_width,
        cam.variant.sensor_height
    );

    if (res <= 0) {
        return ESP_FAIL;
    }

    httpd_resp_send(req, out_json, res);
    return ESP_OK;
}

/*END DIY COTI specific*/

static const httpd_uri_t retireve_values_route = {
    .uri       = "/get",
    .method    = HTTP_GET,
    .handler   = retireve_values,
    .user_ctx  = NULL
};

static const httpd_uri_t echo = {
    .uri       = "/set",
    .method    = HTTP_POST,
    .handler   = post_handler,
    .user_ctx  = NULL
};

esp_err_t index_get_handler(httpd_req_t *req) {
    const uint32_t html_size = index_html_end - index_html_start;
    httpd_resp_set_type(req, "text/html");
    httpd_resp_send(req, (const char *)index_html_start, html_size);
    return ESP_OK;
}

httpd_uri_t index_uri = {
    .uri      = "/",
    .method   = HTTP_GET,
    .handler  = index_get_handler,
    .user_ctx = NULL
};

void app_main(void) {
    ESP_ERROR_CHECK(nvs_flash_init());

    gpio_config_t io_conf = {
        .intr_type = GPIO_INTR_NEGEDGE,   // or GPIO_INTR_POSEDGE, GPIO_INTR_ANYEDGE
        .mode = GPIO_MODE_INPUT,
        .pin_bit_mask = (1ULL << MULTI_BTN),  // Replace GPIO_NUM_0 with your button GPIO
        .pull_down_en = GPIO_PULLDOWN_DISABLE,
        .pull_up_en = GPIO_PULLUP_ENABLE,     // Enable pull-up if button connects to GND
    };
    gpio_config(&io_conf);

    button_debouce = esp_timer_get_time();
    gpio_install_isr_service(0); // 0 for default configuration

    gpio_isr_handler_add(MULTI_BTN, button_isr_handler, NULL);

    bool wifi_en = gpio_get_level(MULTI_BTN) == 0;
    ESP_LOGI(TAG, "Wifi: %d", (int)wifi_en);

    if (wifi_en) {
        ESP_ERROR_CHECK(esp_netif_init());
        ESP_ERROR_CHECK(esp_event_loop_create_default());
        sta_netif = esp_netif_create_default_wifi_ap();
        wifi_init_config_t cfg = WIFI_INIT_CONFIG_DEFAULT();
        ESP_ERROR_CHECK(esp_wifi_init(&cfg));
        ESP_ERROR_CHECK(esp_event_handler_instance_register(WIFI_EVENT,
                                                        ESP_EVENT_ANY_ID,
                                                        &wifi_event_handler,
                                                        NULL,
                                                        NULL));
        ESP_ERROR_CHECK( esp_wifi_set_storage(WIFI_STORAGE_RAM) );
        wifi_config_t wifi_config = {
            .ap = {
                .ssid = SSID,
                .ssid_len = strlen(SSID),
                .password = PASSWORD,
                .channel = 1,
                .max_connection = 4,
                .authmode = WIFI_AUTH_WPA2_PSK,
            }
        };
        ESP_ERROR_CHECK(esp_wifi_set_mode(WIFI_MODE_AP));
        ESP_ERROR_CHECK(esp_wifi_set_config(WIFI_IF_AP, &wifi_config) );
        ESP_ERROR_CHECK(esp_wifi_start());

        vTaskDelay(pdMS_TO_TICKS(2000));
    } else {
        vTaskDelay(pdMS_TO_TICKS(5000));
    }

    for (int i=0; i<PRESET_COUNT; i++) {
        stored.presets[i] = default_preset;
    }
    
    Mini2_init(&cam);

    ESP_ERROR_CHECK(nvs_open("storage", NVS_READWRITE, &flash_handle));
    size_t len = sizeof(stored_values_t);
    esp_err_t err = nvs_get_blob(flash_handle, "stored_values", &stored, &len);
    if (err != ESP_OK) {
        ESP_LOGI(TAG, "Failed to read stores from NVS, going with defaults.");
    }
    Mini2_apply_preset(&cam, &stored.presets[stored.active_preset]);

    xTaskCreate(loop_task, "loop task", 16384, NULL, 5, NULL);

    if (wifi_en) {
        httpd_handle_t server = NULL;
        httpd_config_t config = HTTPD_DEFAULT_CONFIG();
        config.lru_purge_enable = true;

        ESP_LOGI(TAG, "Starting server on port: '%d'", config.server_port);
        if (httpd_start(&server, &config) == ESP_OK) {
            ESP_LOGI(TAG, "Registering URI handlers");
            httpd_register_uri_handler(server, &echo);
            httpd_register_uri_handler(server, &index_uri);
            httpd_register_uri_handler(server, &retireve_values_route);
        }
    }
}

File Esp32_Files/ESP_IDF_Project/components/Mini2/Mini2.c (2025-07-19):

#include "Mini2.h"

uint16_t crc16_xmodem(uint8_t* data, size_t len) {
    uint16_t crc = 0;
    for (int i=0; i<len; i++) {
        crc ^= (data[i] << 8);
        for (int j=0; j<8; j++) {
            if (crc & 0x8000) {
                crc = (crc << 1) ^ 0x1021;
            } else {
                crc <<= 1;
            }
        }
    }
    return crc;
}

void Mini2_init(Mini2_t* cam) {
    uart_config_t uart_config = {
        .baud_rate = 115200,
        .data_bits = UART_DATA_8_BITS,
        .parity = UART_PARITY_DISABLE,
        .stop_bits = UART_STOP_BITS_1,
        .flow_ctrl = UART_HW_FLOWCTRL_DISABLE,
        .source_clk = UART_SCLK_DEFAULT,
    };

    ESP_ERROR_CHECK(uart_driver_install(cam->uart_port, 2048, 0, 0, NULL, 0));
    ESP_ERROR_CHECK(uart_param_config(cam->uart_port, &uart_config));
    ESP_ERROR_CHECK(uart_set_pin(cam->uart_port, cam->uart_tx, cam->uart_rx, -1, -1));
}

esp_err_t Mini2_write_command(Mini2_t* cam, uint8_t* cmd, size_t len) {
    uint8_t full_cmd[] = {0x55, 0x43, 0x49, 0x12, 0x00, 0x00 /*command class*/, 0x00 /*command index*/, 0x00 /*sub command*/, 0x00 /*reserved*/, 0x00, 0x00, 0x00, 0x00 /*4byte Parameter1*/, 0x00, 0x00, 0x00, 0x00 /*4byte Parameter2*/, 0x00, 0x00 /*Read length, 0 when writing*/, 0x00, 0x00 /*2btyes Reserved*/, 0x00, 0x00 /*2byte crc16 xmodem*/};

    if (len > 16) {
        ESP_LOGE(Mini2_TAG, "command length may not be longer than 16bytes");
        return ESP_FAIL;
    }

    memcpy(full_cmd + 5, cmd, len);
    uint16_t checksum = crc16_xmodem(full_cmd + 5, 16);
    memcpy(full_cmd + 21, &checksum, 2);

    ESP_LOG_BUFFER_HEXDUMP(Mini2_TAG, full_cmd, sizeof(full_cmd), ESP_LOG_INFO);
    
    for (int i=0; i < sizeof(full_cmd); i++) {
        int bytes_written = uart_write_bytes(cam->uart_port, full_cmd + i, 1);
        if (bytes_written == -1) {
            ESP_LOGE(Mini2_TAG, "Failed to write byte%d command to UART", i);
            return ESP_FAIL;
        }   
    }

    return ESP_OK;
}

esp_err_t Mini2_set_color_pallet(Mini2_t* cam, enum PseudoColor pseudo_color) {
    uint8_t cmd[] = {0x10, 0x03, 0x45, 0x00, 0x00, pseudo_color};
    return Mini2_write_command(cam, cmd, sizeof(cmd));
}

esp_err_t Mini2_set_scene_mode(Mini2_t* cam, enum SceneMode scene_mode) {
    uint8_t cmd[] = {0x10, 0x04, 0x42, 0x00, scene_mode};
    return Mini2_write_command(cam, cmd, sizeof(cmd));
}

esp_err_t Mini2_set_flip_mode(Mini2_t* cam, enum SceneMode FlipMode) {
    uint8_t cmd[] = {0x10, 0x10, 0x43, 0x00, FlipMode};
    return Mini2_write_command(cam, cmd, sizeof(cmd));
}

esp_err_t Mini2_set_analog_video_format(Mini2_t* cam, enum AnalogVideoFormat av_format) {
    uint8_t cmd[] = {0x10, 0x10, 0x4A, 0x00, 0x01, av_format};
    return Mini2_write_command(cam, cmd, sizeof(cmd));
}

esp_err_t Mini2_set_brightness(Mini2_t* cam, uint8_t brightness) {
    if (brightness > 100) {
        ESP_LOGE(Mini2_TAG, "Brightness must be <= 100");
        return ESP_FAIL;
    }
    uint8_t cmd[] = {0x10, 0x04, 0x47, 0x00, brightness};
    return Mini2_write_command(cam, cmd, sizeof(cmd));
}

esp_err_t Mini2_set_contrast(Mini2_t* cam, uint8_t contrast) {
    if (contrast > 100) {
        ESP_LOGE(Mini2_TAG, "Contrast must be <= 100");
        return ESP_FAIL;
    }
    uint8_t cmd[] = {0x10, 0x04, 0x4A, 0x00, contrast};
    return Mini2_write_command(cam, cmd, sizeof(cmd));
}

esp_err_t Mini2_set_edge_enhancment(Mini2_t* cam, uint8_t gear) {
    if (gear > 2) {
        ESP_LOGE(Mini2_TAG, "Edge enhancment gear must be <= 2");
        return ESP_FAIL;
    }
    uint8_t cmd[] = {0x10, 0x04, 0x4E, 0x00, gear};
    return Mini2_write_command(cam, cmd, sizeof(cmd));
}

esp_err_t Mini2_set_detail_enhancement(Mini2_t* cam, uint8_t gear) {
    if (gear > 100) {
        ESP_LOGE(Mini2_TAG, "Detail enhancement gear must be <= 100");
        return ESP_FAIL;
    }
    uint8_t cmd[] = {0x10, 0x03, 0x85, 0x00, gear};
    return Mini2_write_command(cam, cmd, sizeof(cmd));
}

esp_err_t Mini2_set_burn_protection(Mini2_t* cam, bool enabled) {
    uint8_t cmd[] = {0x10, 0x03, 0x4B, 0x00, (uint8_t)enabled};
    return Mini2_write_command(cam, cmd, sizeof(cmd));
}

esp_err_t Mini2_set_shutter_position(Mini2_t* cam, bool open) {
    uint8_t cmd[] = {0x01, 0x0F, 0x45, 0x00, (uint8_t)open};
    return Mini2_write_command(cam, cmd, sizeof(cmd));
}

esp_err_t Mini2_set_auto_shutter(Mini2_t* cam, bool enabled) {
    uint8_t cmd[] = {0x10, 0x02, 0x41, 0x00, (uint8_t)enabled};
    return Mini2_write_command(cam, cmd, sizeof(cmd));
}

esp_err_t Mini2_set_centre_zoom(Mini2_t* cam, uint8_t zoom) {
    if (zoom < 10 || zoom > 80 ) {
        ESP_LOGE(Mini2_TAG, "Zoom must be between 10 and 80 for 1x to 8x");
        return ESP_FAIL;
    }

    uint8_t cmd[] = {0x01, 0x31, 0x42, 0x00, 0x00, zoom};
    return Mini2_write_command(cam, cmd, sizeof(cmd));
}

esp_err_t Mini2_set_point_zoom(Mini2_t* cam, uint16_t x, uint16_t y, uint8_t zoom) {
    if (zoom < 10 || zoom > 80 ) {
        ESP_LOGE(Mini2_TAG, "Zoom must be between 10 and 80 for 1x to 8x");
        return ESP_FAIL;
    }
    if (x > cam->variant.sensor_width) {
        ESP_LOGE(Mini2_TAG, "X must be between 0 and sensor width");
        return ESP_FAIL;
    }
    if (y > cam->variant.sensor_height) {
        ESP_LOGE(Mini2_TAG, "Y must be between 0 and sensor height");
        return ESP_FAIL;
    }

    ESP_LOGI(Mini2_TAG, "Setting %.1fzoom at %dx, %dy", ((float)zoom / 10.0), (int)x, (int)y);

    uint8_t cmd[] = {0x01, 0x31, 0x51, 0x00, 0x00, zoom, 0x00, 0x00, *((uint8_t*)&x), *(((uint8_t*)&x) + 1)/*X*/, *((uint8_t*)&y), *(((uint8_t*)&y) + 1) /*Y*/};
    return Mini2_write_command(cam, cmd, sizeof(cmd));
}

esp_err_t Mini2_set_detector_fps(Mini2_t* cam, enum DetectorRefreshRate fps) {
    if (!(fps == cam->variant.low_fps || fps == cam->variant.high_fps)) {
        ESP_LOGE(Mini2_TAG, "Selected variant doesn't support this detector fps.");
        return ESP_FAIL;
    }
    uint8_t cmd[] = {0x10, 0x10, 0x44, 0x00, fps};
    return Mini2_write_command(cam, cmd, sizeof(cmd));
}

esp_err_t Mini2_set_sleep(Mini2_t* cam, bool sleep) {
    uint8_t cmd[] = {0x10, 0x10, 0x48, 0x00, (uint8_t)sleep};
    return Mini2_write_command(cam, cmd, sizeof(cmd));
}

esp_err_t Mini2_set_crosshair(Mini2_t* cam, bool enable) {
    uint8_t cmd[] = {0x10, 0x11, 0x57, 0x00, (uint8_t)enable};
    return Mini2_write_command(cam, cmd, sizeof(cmd));
}

esp_err_t Mini2_parameters_save(Mini2_t* cam) {
    uint8_t cmd[] = {0x10, 0x10, 0x51};
    return Mini2_write_command(cam, cmd, sizeof(cmd));
}

esp_err_t Mini2_restore_factory_parameters(Mini2_t* cam) {
    uint8_t cmd[] = {0x10, 0x10, 0x52};
    return Mini2_write_command(cam, cmd, sizeof(cmd));
}

esp_err_t Mini2_NUC(Mini2_t* cam) {
    uint8_t cmd[] = {0x10, 0x2, 0x43};
    return Mini2_write_command(cam, cmd, sizeof(cmd));
}

esp_err_t Mini2_Background_Correction(Mini2_t* cam) {
    uint8_t cmd[] = {0x1, 0x10, 0x52};
    return Mini2_write_command(cam, cmd, sizeof(cmd));
}
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

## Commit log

2025-07-15 Fixed some typos. Added Alibab-link for CV256 9.1mm
2025-07-19 Added mirror options. Updated firmware to fully support presets. Change amount of presets to 5 for now. Added parts to User Manual. Added bunch of CameraCage offsets to choose from, use FreeCad file 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
    [CameraCage_1_0_deg.step, CameraCage_1_1_deg.step, CameraCage_1_2_deg.step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]
2025-07-19 Made the Hole size for M2 inserts parametric, so you can change it it you have inserts with a slightly different OD
    [DIY_COTI.FCStd]
2025-07-22 Added pictures for the surface mirror assembly. The mirror will be replaced by a prism, but if you've already bought a mirror you can still use it.
2025-07-22 Now uses prism instead of mirror, check change-history for previous commit for mirror steps incase you already bought one
    [CameraCag.step, CameraCage_1_2_deg.step, DIY_COTI.FCStd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]
